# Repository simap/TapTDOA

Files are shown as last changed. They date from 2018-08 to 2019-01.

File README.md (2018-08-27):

TapTDOA
===============

TapTDOA is a project to explore the possibility of making a generic tap interface controller. 

[See Hackaday project for details](https://hackaday.io/project/159821-taptdoa)

License
===============

Portions of the code are provided by third parties, see below for licensing information for those portions. This includes the ARM Math and DSP library as well as STM drivers and HAL code used for setting up the microcontroller.

The MIT License

Copyright (c) 2018 Ben Hencke

Permission is hereby granted, free of charge, to any person obtaining a copy
of this software and associated documentation files (the "Software"), to deal
in the Software without restriction, including without limitation the rights
to use, copy, modify, merge, publish, distribute, sublicense, and/or sell
copies of the Software, and to permit persons to whom the Software is
furnished to do so, subject to the following conditions:

The above copyright notice and this permission notice shall be included in all
copies or substantial portions of the Software.

THE SOFTWARE IS PROVIDED "AS IS", WITHOUT WARRANTY OF ANY KIND, EXPRESS OR
IMPLIED, INCLUDING BUT NOT LIMITED TO THE WARRANTIES OF MERCHANTABILITY,
FITNESS FOR A PARTICULAR PURPOSE AND NONINFRINGEMENT. IN NO EVENT SHALL THE
AUTHORS OR COPYRIGHT HOLDERS BE LIABLE FOR ANY CLAIM, DAMAGES OR OTHER
LIABILITY, WHETHER IN AN ACTION OF CONTRACT, TORT OR OTHERWISE, ARISING FROM,
OUT OF OR IN CONNECTION WITH THE SOFTWARE OR THE USE OR OTHER DEALINGS IN THE
SOFTWARE.

----------

Portions of code are provided by ARM Limited and have the following license:

    Copyright (C) 2010-2015 ARM Limited. All rights reserved.

    $Date:        20. October 2015
    $Revision:    V1.4.5 b

    Project:      CMSIS DSP Library
    Title:        arm_math.h

    Description:  Public header file for CMSIS DSP Library

    Target Processor: Cortex-M7/Cortex-M4/Cortex-M3/Cortex-M0

    Redistribution and use in source and binary forms, with or without
    modification, are permitted provided that the following conditions
    are met:
     - Redistributions of source code must retain the above copyright
       notice, this list of conditions and the following disclaimer.
     - Redistributions in binary form must reproduce the above copyright
       notice, this list of conditions and the following disclaimer in
       the documentation and/or other materials provided with the
       distribution.
     - Neither the name of ARM LIMITED nor the names of its contributors
       may be used to endorse or promote products derived from this
       software without specific prior written permission.

    THIS SOFTWARE IS PROVIDED BY THE COPYRIGHT HOLDERS AND CONTRIBUTORS
    "AS IS" AND ANY EXPRESS OR IMPLIED WARRANTIES, INCLUDING, BUT NOT
    LIMITED TO, THE IMPLIED WARRANTIES OF MERCHANTABILITY AND FITNESS
    FOR A PARTICULAR PURPOSE ARE DISCLAIMED. IN NO EVENT SHALL THE
    COPYRIGHT OWNER OR CONTRIBUTORS BE LIABLE FOR ANY DIRECT, INDIRECT,
    INCIDENTAL, SPECIAL, EXEMPLARY, OR CONSEQUENTIAL DAMAGES (INCLUDING,
    BUT NOT LIMITED TO, PROCUREMENT OF SUBSTITUTE GOODS OR SERVICES;
    LOSS OF USE, DATA, OR PROFITS; OR BUSINESS INTERRUPTION) HOWEVER
    CAUSED AND ON ANY THEORY OF LIABILITY, WHETHER IN CONTRACT, STRICT
    LIABILITY, OR TORT (INCLUDING NEGLIGENCE OR OTHERWISE) ARISING IN
    ANY WAY OUT OF THE USE OF THIS SOFTWARE, EVEN IF ADVISED OF THE
    POSSIBILITY OF SUCH DAMAGE.

---------

Portions of code are provided by STMicroelectronics International N.V. and have the following license:

    Copyright (c) 2018 STMicroelectronics International N.V. 
    All rights reserved.

    Redistribution and use in source and binary forms, with or without 
    modification, are permitted, provided that the following conditions are met:

    1. Redistribution of source code must retain the above copyright notice, 
      this list of conditions and the following disclaimer.
    2. Redistributions in binary form must reproduce the above copyright notice,
      this list of conditions and the following disclaimer in the documentation
      and/or other materials provided with the distribution.
    3. Neither the name of STMicroelectronics nor the names of other 
      contributors to this software may be used to endorse or promote products 
      derived from this software without specific written permission.
    4. This software, including modifications and/or derivative works of this 
      software, must execute solely and exclusively on microcontroller or
      microprocessor devices manufactured by or for STMicroelectronics.
    5. Redistribution and use of this software other than as permitted under 
      this license is void and will automatically terminate your rights under 
      this license. 

    THIS SOFTWARE IS PROVIDED BY STMICROELECTRONICS AND CONTRIBUTORS "AS IS" 
    AND ANY EXPRESS, IMPLIED OR STATUTORY WARRANTIES, INCLUDING, BUT NOT 
    LIMITED TO, THE IMPLIED WARRANTIES OF MERCHANTABILITY, FITNESS FOR A 
    PARTICULAR PURPOSE AND NON-INFRINGEMENT OF THIRD PARTY INTELLECTUAL PROPERTY
    RIGHTS ARE DISCLAIMED TO THE FULLEST EXTENT PERMITTED BY LAW. IN NO EVENT 
    SHALL STMICROELECTRONICS OR CONTRIBUTORS BE LIABLE FOR ANY DIRECT, INDIRECT,
    INCIDENTAL, SPECIAL, EXEMPLARY, OR CONSEQUENTIAL DAMAGES (INCLUDING, BUT NOT
    LIMITED TO, PROCUREMENT OF SUBSTITUTE GOODS OR SERVICES; LOSS OF USE, DATA, 
    OR PROFITS; OR BUSINESS INTERRUPTION) HOWEVER CAUSED AND ON ANY THEORY OF 
    LIABILITY, WHETHER IN CONTRACT, STRICT LIABILITY, OR TORT (INCLUDING 
    NEGLIGENCE OR OTHERWISE) ARISING IN ANY WAY OUT OF THE USE OF THIS SOFTWARE,
    EVEN IF ADVISED OF THE POSSIBILITY OF SUCH DAMAGE.

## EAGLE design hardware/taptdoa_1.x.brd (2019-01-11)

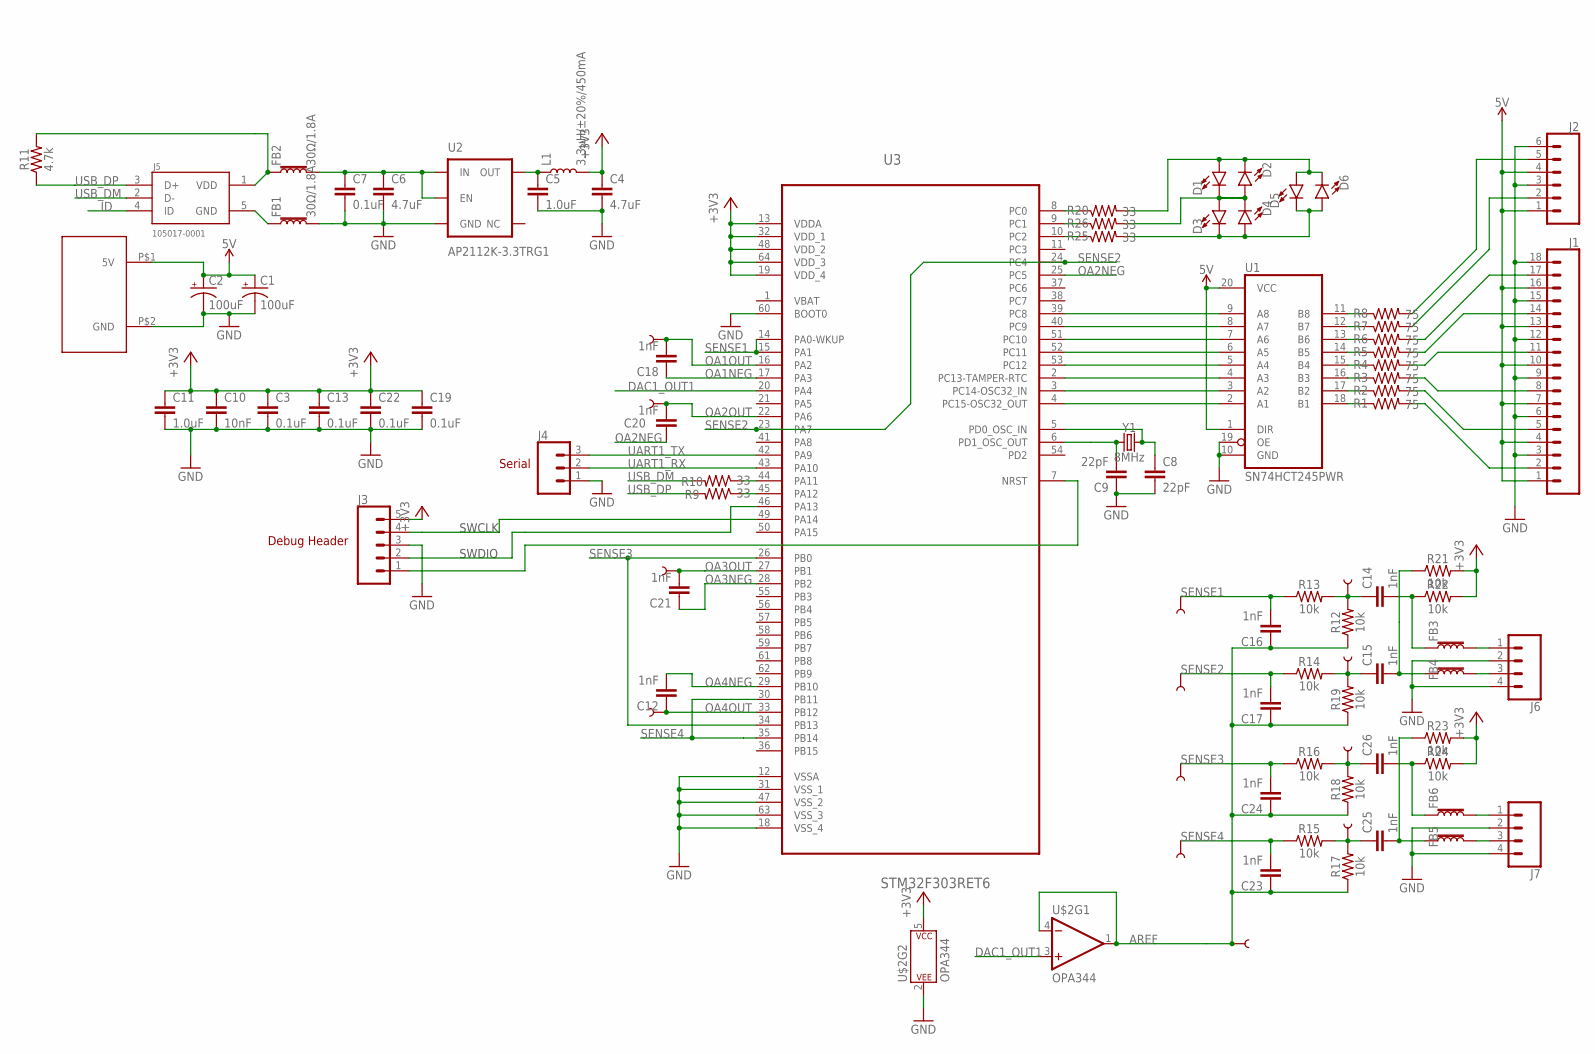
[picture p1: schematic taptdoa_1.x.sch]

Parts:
C1, C2: 100uF; PANASONIC_D
C3, C7, C13, C19, C22: 0.1uF; 0603
C4, C6: 4.7uF; 0603
C5, C11: 1.0uF; 0603
C8, C9: 22pF; 0603
C10: 10nF; 0603
C12, C14, C15, C16, C17, C18, C20, C21, C23, C24, C25, C26: 1nF; 0603
D1, D2, D3, D4, D5, D6: LED0603; LED-0603
FB1, FB2, FB3, FB4, FB5, FB6: 30Ω/1.8A; 0603
J1: CONN_18; 1X18
J2: CONN_06LOCK; 1X06_LOCK
J3: CONN_05LOCK; 1X05_LOCK
J4: CONN_03; 1X03
J5: 105017-0001; MOLEX_105017-0001
J6, J7: CONN_04LOCK_LONGPADS; 1X04_LOCK_LONGPADS
L1: 3.3µH/±20%/450mA; 0805
R1, R2, R3, R4, R5, R6, R7, R8: 75; 0603
R9, R10, R20, R25, R26: 33; 0603
R11: 4.7k; 0603
R12, R13, R14, R15, R16, R17, R18, R19, R21, R22, R23, R24: 10k; 0603
TP1, TP2, TP3, TP4, TP5, TP6, TP7, TP8, TP9, TP10, TP11, TP12, TP13: TEST-POINT3X4; PAD.03X.04
U1: SN74HCT245PWR; TSSOP20
U2: AP2112K-3.3TRG1; SOT23-5
U3: STM32F303RET6; QFP50P1200X1200X160-64N
U$1: XT30XT30_THRUHOLE; ZT30
U$2: OPA344; SOT23-5
Y1: 8MHz; HC49UP

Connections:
5V: C1.+, C2.+, J1.1, J1.4, J1.7, J1.10, J1.13, J1.16, J2.1, J2.4, U1.1 (DIR), U1.20 (VCC), U$1.P$1 (5V)
+3V3: C3.1, C4.1, C10.1, C11.1, C13.1, C19.1, C22.1, J3.5, L1.2, R21.2, R22.2, R23.2, R24.2, U3.13 (VDDA), U3.19 (VDD_4), U3.32 (VDD_1), U3.48 (VDD_2), U3.64 (VDD_3), U$2.5 (P$V+)
AREF: C16.1, C17.1, C23.1, C24.1, R12.1, R17.1, R18.1, R19.1, TP8.P$1, U$2.1 (OUT), U$2.4 (-IN)
DAC1_OUT1: U3.20 (PA4), U$2.3 (+IN)
GND: C1.-, C2.-, C3.2, C4.2, C5.2, C6.2, C7.2, C8.2, C9.1, C10.2, C11.2, C13.2, C19.2, C22.2, FB1.2, J1.3, J1.6, J1.9, J1.12, J1.15, J1.18, J2.3, J2.6, J3.3, J4.1, J6.2, J6.4, J7.2, J7.4, U1.10 (GND), U1.19 (OE), U2.2 (GND), U3.12 (VSSA), U3.18 (VSS_4), U3.31 (VSS_1), U3.47 (VSS_2), U3.60 (BOOT0), U3.63 (VSS_3), U$1.P$2 (GND), U$2.2 (P$V-)
HP1: C14.1, R12.2, R13.2, TP2.P$1
HP2: C15.1, R14.2, R19.2, TP3.P$1
HP3: C26.1, R16.2, R18.2, TP12.P$1
HP4: C25.1, R15.2, R17.2, TP13.P$1
ID: J5.4 (ID)
LED0: J1.2, R1.2
LED1: J1.5, R2.2
LED2: J1.8, R3.2
LED3: J1.11, R4.2
LED4: J1.14, R5.2
LED5: J1.17, R6.2
unnamed: R20.1, U3.8 (PC0)
unnamed: D1.A, D2.C, D5.A, D6.C, R20.2
unnamed: R25.1, U3.10 (PC2)
unnamed: R26.1, U3.9 (PC1)
unnamed: D1.C, D2.A, D3.A, D4.C, R26.2
unnamed: R10.1, U3.44 (PA11)
unnamed: R9.1, U3.45 (PA12)
unnamed: FB1.1, J5.5 (GND)
unnamed: C5.1, L1.1, U2.5 (OUT)
unnamed: R1.1, U1.18 (B1)
unnamed: R2.1, U1.17 (B2)
unnamed: R3.1, U1.16 (B3)
unnamed: R4.1, U1.15 (B4)
unnamed: R5.1, U1.14 (B5)
unnamed: R6.1, U1.13 (B6)
unnamed: C14.2, FB3.1, R22.1
unnamed: C26.2, FB6.1, R24.1
unnamed: C15.2, FB4.1, R21.1
unnamed: D3.C, D4.A, D5.C, D6.A, R25.2
unnamed: C25.2, FB5.1, R23.1
unnamed: R7.1, U1.12 (B7)
unnamed: R8.1, U1.11 (B8)
unnamed: J2.2, R7.2
unnamed: J2.5, R8.2
unnamed: FB3.2, J6.1
unnamed: FB6.2, J7.1
unnamed: FB5.2, J7.3
unnamed: FB4.2, J6.3
NRST: J3.1, U3.7 (NRST)
OA1NEG: C18.1, U3.17 (PA3)
OA1OUT: C18.2, TP6.P$1, U3.16 (PA2)
OA2NEG: C20.1, U3.25 (PC5)
OA2OUT: C20.2, TP7.P$1, U3.22 (PA6)
OA3NEG: C21.1, U3.28 (PB2)
OA3OUT: C21.2, TP9.P$1, U3.27 (PB1)
OA4NEG: C12.2, U3.29 (PB10)
OA4OUT: C12.1, TP1.P$1, U3.33 (PB12)
PA13: J3.2, U3.46 (PA13)
PA14: J3.4, U3.49 (PA14)
PC8: U1.9 (A8), U3.39 (PC8)
PC9: U1.8 (A7), U3.40 (PC9)
PC10: U1.7 (A6), U3.51 (PC10)
PC11: U1.6 (A5), U3.52 (PC11)
PC12: U1.5 (A4), U3.53 (PC12)
PC13: U1.4 (A3), U3.2 (PC13-TAMPER-RTC)
PC14: U1.3 (A2), U3.3 (PC14-OSC32_IN)
PC15: U1.2 (A1), U3.4 (PC15-OSC32_OUT)
PD0_OSC_IN: C8.1, U3.5 (PD0_OSC_IN), Y1.2
PD1_OSC_OUT: C9.2, U3.6 (PD1_OSC_OUT), Y1.1
SENSE1: C16.2, R13.1, TP4.P$1, U3.14 (PA0-WKUP), U3.15 (PA1)
SENSE2: C17.2, R14.1, TP5.P$1, U3.23 (PA7), U3.24 (PC4)
SENSE3: C24.2, R16.1, TP10.P$1, U3.26 (PB0), U3.34 (PB13)
SENSE4: C23.2, R15.1, TP11.P$1, U3.30 (PB11), U3.35 (PB14)
UART1_RX: J4.2, U3.43 (PA10)
UART1_TX: J4.3, U3.42 (PA9)
USB_DM: J5.2 (D-), R10.2
USB_DP: J5.3 (D+), R9.2, R11.1
VUSB: FB2.1, J5.1 (VDD), R11.2
VUSB2: C6.1, C7.1, FB2.2, U2.1 (IN), U2.3 (EN)

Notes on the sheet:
SWDIO
SWCLK
Debug Header
Serial

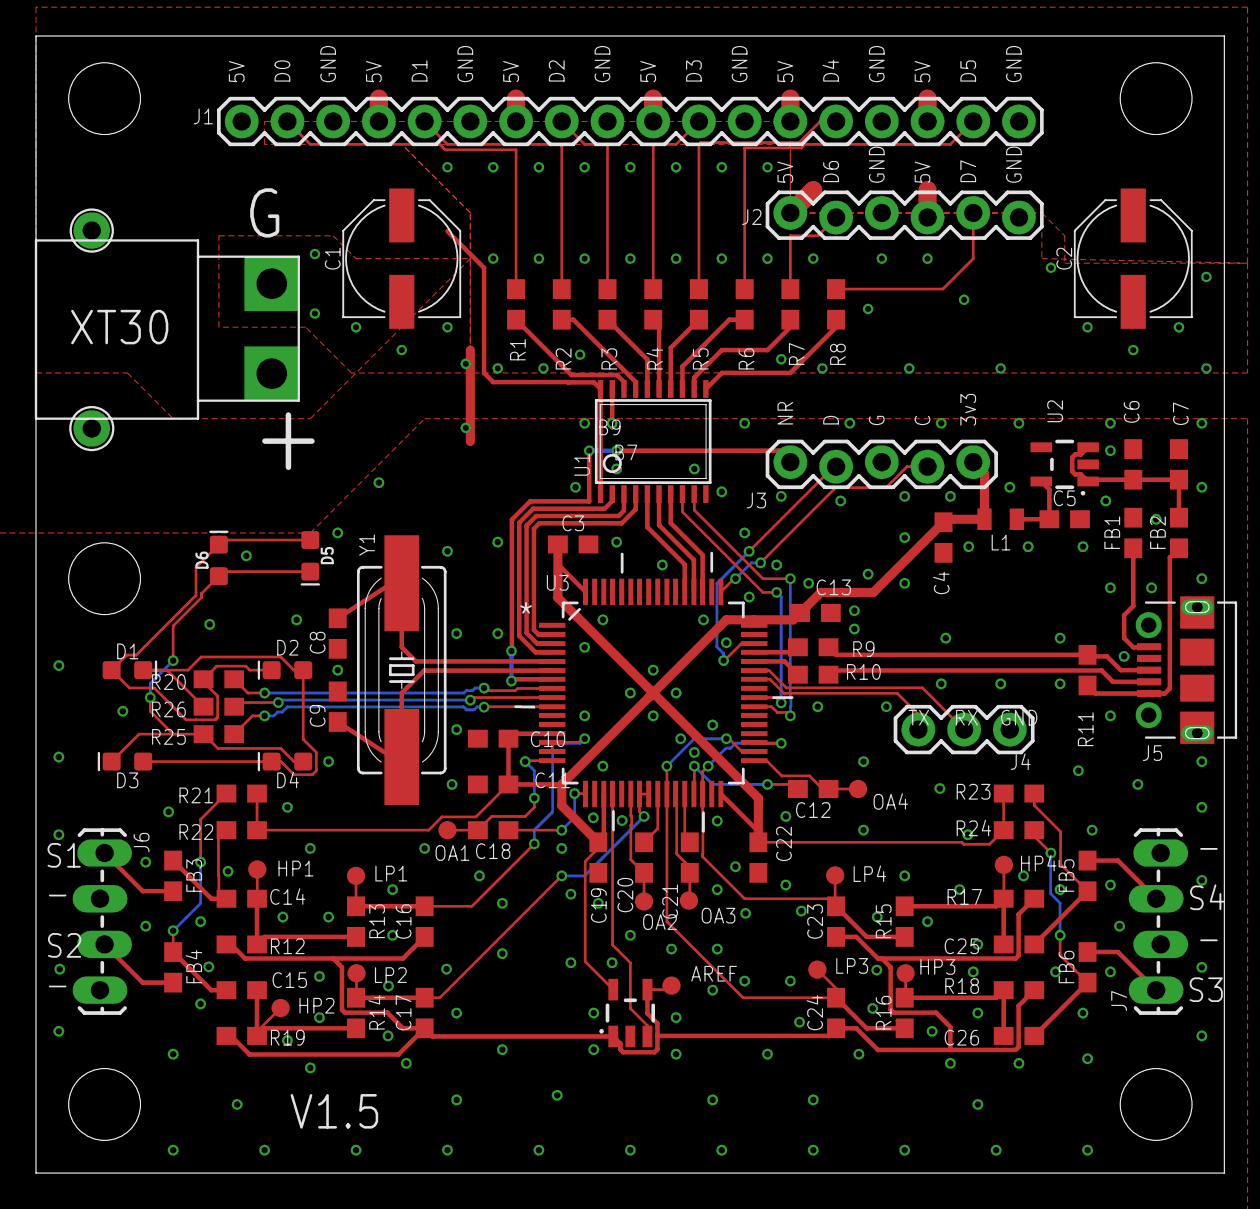
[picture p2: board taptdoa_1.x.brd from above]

Board: 2 copper layers, 66.0 x 63.2 mm, 91 parts (0 on the bottom side), 74 nets.

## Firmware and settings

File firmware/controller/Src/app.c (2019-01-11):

#include "stm32f3xx_hal.h"
#include "usb_device.h"
#include "pixelBlaster.h"
#include "console.h"


#include "app.h"


int _write(int file, char *outgoing, int len);

extern ADC_HandleTypeDef hadc1;
extern ADC_HandleTypeDef hadc2;
extern ADC_HandleTypeDef hadc3;
extern ADC_HandleTypeDef hadc4;
extern DMA_HandleTypeDef hdma_adc1;
extern DMA_HandleTypeDef hdma_adc2;
extern DMA_HandleTypeDef hdma_adc3;
extern DMA_HandleTypeDef hdma_adc4;

extern DAC_HandleTypeDef hdac1;

extern OPAMP_HandleTypeDef hopamp1;
extern OPAMP_HandleTypeDef hopamp2;
extern OPAMP_HandleTypeDef hopamp3;
extern OPAMP_HandleTypeDef hopamp4;

extern TIM_HandleTypeDef htim4;
extern DMA_HandleTypeDef hdma_tim4_up;

extern UART_HandleTypeDef huart1;

extern const uint16_t sample1[];
extern const uint16_t sample2[];
extern const uint16_t sample3[];
extern const uint16_t sample4[];

#define LED_BUFFER_SIZE (40*24*8/2)
uint8_t ledBuffer[LED_BUFFER_SIZE];
PixelBlasterData pb;


int16_t cbuf[4][ADC_BUF_SIZE];

static volatile bool triggerDone = false;
int dmaCndtr;

volatile uint32_t ms;
uint32_t lastHitMs = 0;

volatile enum {
	WAITING, CAPTURING, IGNORENEXT
} triggerMode;

/*
 * Set up timer 3 to trigger all ADCs at the same time.
 * simultaneously capture all channels
 * It also seems like it will be more controllable than continuous mode.
 * DMA buffers won't need too much upkeep, should mostly run w/o cpu
 * Use adc watchdog 1 on each adc to trigger captureEvent()
 *
 *           trigger   +------+ dma   +---------------+
 *           +-------> | adc1 +------>+  circ buffer  |
 *           |         +------+       +---------------+
 *           |         +------+ dma   +---------------+
 *           +-------> | adc2 +------>+  circ buffer  |
 * +------+  |         +------+       +---------------+
 * | tim3 +--+         +------+ dma   +---------------+
 * +------+  +-------> | adc3 +------>+  circ buffer  |
 *           |         +------+       +---------------+
 *           |         +------+ dma   +---------------+
 *           +-------> | adc4 +------>+  circ buffer  |
 *                     +--+---+       +---------------+
 *                        |
 *                        |adc 1-4 watchdogs
 *                        +------------------->  captureEvent()
 *
 * When event fires, make note of current dma CNDTR indicating where the circular buffer is at the trigger start
 * start countdown on tim3 triggers until we have the trailing data captured
 * then stop tim3 to process the buffer
 *
 * TODO is it possible one adc triggered an event and there's nothing on the others?
 * TODO any issue with being "blind" during processing/sending?
 * TODO ws2812: if we need to interrupt at 800khz, thats about every 90 cycles. too much? maybe clock stretch?
 */

void setAdcWd() {
	int w = 1300, m;
	uint32_t tr1;

	m = getMeian(0);
	tr1 = ((m + w) << 16) | (m - w);
	ADC1->TR1 = tr1;

	m = getMeian(1);
	tr1 = ((m + w) << 16) | (m - w);
	ADC2->TR1 = tr1;

	m = getMeian(2);
	tr1 = ((m + w) << 16) | (m - w);
	ADC3->TR1 = tr1;

	m = getMeian(3);
	tr1 = ((m + w) << 16) | (m - w);
	ADC4->TR1 = tr1;
}

void setOpAmpGainAndDac(int gain) {

	//	VM_SEL
	//	10: Resistor feedback output (PGA mode)
	//	11: follower mode
	uint32_t csr = 0;
	switch(gain) {
		case 1:
			csr = 0b11 << OPAMP1_CSR_VMSEL_Pos; //set to follower
			break;
		case 2:
			csr = OPAMP_PGA_GAIN_2 | 0b10 << OPAMP1_CSR_VMSEL_Pos;
			break;
		case 4:
			csr = OPAMP_PGA_GAIN_4 | 0b10 << OPAMP1_CSR_VMSEL_Pos;
			break;
		case 8:
			csr = OPAMP_PGA_GAIN_8 | 0b10 << OPAMP1_CSR_VMSEL_Pos;
			break;
		case 16:
			csr = OPAMP_PGA_GAIN_16 | 0b10 << OPAMP1_CSR_VMSEL_Pos;
			break;
		default:
			HardFault_Handler();
	}

	HAL_DACEx_DualSetValue(&hdac1, DAC_ALIGN_12B_R, 2048/gain, 2048/gain);

	MODIFY_REG(hopamp1.Instance->CSR, OPAMP_CSR_PGGAIN_Msk | OPAMP_CSR_VMSEL_Msk, csr);
	MODIFY_REG(hopamp2.Instance->CSR, OPAMP_CSR_PGGAIN_Msk | OPAMP_CSR_VMSEL_Msk, csr);
	MODIFY_REG(hopamp3.Instance->CSR, OPAMP_CSR_PGGAIN_Msk | OPAMP_CSR_VMSEL_Msk, csr);
	MODIFY_REG(hopamp4.Instance->CSR, OPAMP_CSR_PGGAIN_Msk | OPAMP_CSR_VMSEL_Msk, csr);

}

void setup() {

	pbInit(&pb, ledBuffer, LED_BUFFER_SIZE);
	memset(ledBuffer, 0, LED_BUFFER_SIZE);

	HAL_DACEx_DualSetValue(&hdac1, DAC_ALIGN_12B_R, 2048/4, 2048/4);

//	setOpAmpGainAndDac(4);

//	MODIFY_REG(hopamp1.Instance->CSR, OPAMP_CSR_PGGAIN_Msk, OPAMP_PGA_GAIN_2);
//	MODIFY_REG(hopamp2.Instance->CSR, OPAMP_CSR_PGGAIN_Msk, OPAMP_PGA_GAIN_2);
//	MODIFY_REG(hopamp3.Instance->CSR, OPAMP_CSR_PGGAIN_Msk, OPAMP_PGA_GAIN_2);
//	MODIFY_REG(hopamp4.Instance->CSR, OPAMP_CSR_PGGAIN_Msk, OPAMP_PGA_GAIN_2);

	HAL_DAC_Start(&hdac1, DAC_CHANNEL_1);

	HAL_Delay(100);

	HAL_ADCEx_Calibration_Start(&hadc1, ADC_SINGLE_ENDED);
	HAL_ADCEx_Calibration_Start(&hadc2, ADC_SINGLE_ENDED);
	HAL_ADCEx_Calibration_Start(&hadc3, ADC_SINGLE_ENDED);
	HAL_ADCEx_Calibration_Start(&hadc4, ADC_SINGLE_ENDED);

	//TODO try without calibrating, seems off anyway.
	HAL_OPAMP_SelfCalibrate(&hopamp1);
	HAL_OPAMP_SelfCalibrate(&hopamp2);
	HAL_OPAMP_SelfCalibrate(&hopamp3);
	HAL_OPAMP_SelfCalibrate(&hopamp4);

	HAL_OPAMP_Start(&hopamp1);
	HAL_OPAMP_Start(&hopamp2);
	HAL_OPAMP_Start(&hopamp3);
	HAL_OPAMP_Start(&hopamp4);

	HAL_ADC_Start_DMA(&hadc1, (uint32_t *) &cbuf[0][0], ADC_BUF_SIZE);
	HAL_ADC_Start_DMA(&hadc2, (uint32_t *) &cbuf[1][0], ADC_BUF_SIZE);
	HAL_ADC_Start_DMA(&hadc3, (uint32_t *) &cbuf[2][0], ADC_BUF_SIZE);
	HAL_ADC_Start_DMA(&hadc4, (uint32_t *) &cbuf[3][0], ADC_BUF_SIZE);

	disarmAdcWatchdogs();



	//let things settle on powerup
	HAL_Delay(100);

//	DBGMCU->APB1FZ = 0xffff;
//	DBGMCU->APB2FZ = 0xffff;

	LL_TIM_ClearFlag_UPDATE(TIM3);
	LL_TIM_EnableIT_UPDATE(TIM3);

	LL_TIM_ClearFlag_UPDATE(TIM2);
	LL_TIM_EnableIT_UPDATE(TIM2);

	LL_TIM_EnableCounter(TIM3);
	LL_TIM_EnableCounter(TIM4);

	//tim4 is used to spit out pixel data to gpio
	TIM4->DIER |= TIM_DIER_UDE; //Update DMA request enable
	HAL_TIM_Base_Start(&htim4);

	HAL_Delay(100);

	seedMeans(cbuf);

	setAdcWd();
	armAdcWatchdogs();
}

void disarmAdcWatchdogs(void) {
	CLEAR_BIT(hadc1.Instance->IER, ADC_IER_AWD1IE);
	CLEAR_BIT(hadc2.Instance->IER, ADC_IER_AWD1IE);
	CLEAR_BIT(hadc3.Instance->IER, ADC_IER_AWD1IE);
	CLEAR_BIT(hadc4.Instance->IER, ADC_IER_AWD1IE);
}

void armAdcWatchdogs(void) {
	CLEAR_BIT(ADC1->ISR, ADC_ISR_AWD1);
	CLEAR_BIT(ADC2->ISR, ADC_ISR_AWD1);
	CLEAR_BIT(ADC3->ISR, ADC_ISR_AWD1);
	CLEAR_BIT(ADC4->ISR, ADC_ISR_AWD1);

	SET_BIT(hadc1.Instance->IER, ADC_IER_AWD1IE);
	SET_BIT(hadc2.Instance->IER, ADC_IER_AWD1IE);
	SET_BIT(hadc3.Instance->IER, ADC_IER_AWD1IE);
	SET_BIT(hadc4.Instance->IER, ADC_IER_AWD1IE);
}



uint32_t helloTimer;

void loop() {
	if (ms - helloTimer > 5000) {
		helloTimer = ms;
		printf("hi\n");
		flushConsole();
	}

#if 0
	memcpy(cbuf[0], sample1 + 1500, ADC_BUF_SIZE * sizeof(q15_t));
	memcpy(cbuf[1], sample2 + 1500, ADC_BUF_SIZE * sizeof(q15_t));
	memcpy(cbuf[2], sample3 + 1500, ADC_BUF_SIZE * sizeof(q15_t));
	memcpy(cbuf[3], sample4 + 1500, ADC_BUF_SIZE * sizeof(q15_t));

	analyzeDelays(cbuf, 0);
	HAL_Delay(1000);

	return;

#endif

	if (HAL_DMA_GetState(&hdma_tim4_up) == HAL_DMA_STATE_READY && pbCheckDone(&pb)) {
		//TODO reset the timer counter or it can cut clocks, this seems to transfer immediately
		htim4.Instance->CNT = 0;
		HAL_DMA_Start_IT(&hdma_tim4_up, (uint32_t) ledBuffer, ((uint32_t)&GPIOC->ODR) + 1, LED_BUFFER_SIZE);
	}

	if (triggerDone) {
		if (ms - lastHitMs > 500) {

			int res = analyzeDelays(cbuf, dmaCndtr);

			flushConsole();
#if 0
			printf("Raw data:\nch1\tch2\tch3\tch4\n");

			union {
				uint32_t vars[4];
				char bytes[20];
			} buf;

			for (int i = 0; i < ADC_BUF_SIZE; i++) {
				int index = (ADC_BUF_SIZE + i - dmaCndtr + 1) % ADC_BUF_SIZE;
				buf.vars[0] = hexShort(cbuf[0][index]);
				buf.vars[1] = hexShort(cbuf[1][index]);
				buf.vars[2] = hexShort(cbuf[2][index]);
				buf.vars[3] = hexShort(cbuf[3][index]);
				buf.bytes[16] = '\n';
				_write(0, buf.bytes, 17);
			}
			printf("=========\n");
			flushConsole();
#endif
			lastHitMs = ms;
		}

		LL_TIM_EnableCounter(TIM3);
		HAL_Delay(2);

		triggerDone = false;
		//TODO figure out why adc watchdog keeps firing immediately after it gets reenabled
		triggerMode = WAITING;
		armAdcWatchdogs();
	}

}

void startEventCapture() {

	disarmAdcWatchdogs();
	triggerMode = CAPTURING;

	LL_TIM_EnableCounter(TIM2);
}

//called from TIM2_IRQHandler
void stopEventCapture() {
	if (triggerMode == CAPTURING) {
		LL_TIM_DisableCounter(TIM3);
		triggerDone = true;
		dmaCndtr = hdma_adc1.Instance->CNDTR; //these should all be the same
	}
}

void HAL_ADC_LevelOutOfWindowCallback(ADC_HandleTypeDef* hadc) {
	startEventCapture();
}

void HAL_SYSTICK_Callback() {
	ms++;
}

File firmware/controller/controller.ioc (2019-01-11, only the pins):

Mcu.UserName=STM32F303RETx
PA0.Signal=ADC1_IN1
PA1.Signal=OPAMP1_VINP
PA10.GPIO_Label=uartRx
PA10.Signal=USART1_RX
PA11.Signal=USB_DM
PA12.Signal=USB_DP
PA13.Signal=SYS_JTMS-SWDIO
PA14.Signal=SYS_JTCK-SWCLK
PA2.Signal=OPAMP1_VOUT
PA3.Signal=OPAMP1_VINM
PA4.Signal=COMP_DAC11_group
PA5.Signal=COMP_DAC12_group
PA6.Signal=OPAMP2_VOUT
PA7.Signal=OPAMP2_VINP
PA9.GPIO_Label=uartTx
PA9.Signal=USART1_TX
PB0.Signal=OPAMP3_VINP
PB1.Signal=OPAMP3_VOUT
PB10.Signal=OPAMP4_VINM
PB11.Signal=OPAMP4_VINP
PB12.Signal=OPAMP4_VOUT
PB13.Signal=ADC3_IN5
PB14.Signal=ADC4_IN4
PB2.Signal=OPAMP3_VINM
PC0.Signal=S_TIM1_CH1
PC1.Signal=S_TIM1_CH2
PC10.Signal=GPIO_Output
PC11.Signal=GPIO_Output
PC12.Signal=GPIO_Output
PC13.Signal=GPIO_Output
PC14-OSC32_IN.Signal=GPIO_Output
PC15-OSC32_OUT.Signal=GPIO_Output
PC4.Signal=ADC2_IN5
PC5.Signal=OPAMP2_VINM
PC8.Signal=GPIO_Output
PC9.Signal=GPIO_Output
PF0-OSC_IN.Signal=RCC_OSC_IN
PF1-OSC_OUT.Signal=RCC_OSC_OUT

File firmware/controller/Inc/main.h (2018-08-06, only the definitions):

#define uartTx_Pin GPIO_PIN_9
#define uartTx_GPIO_Port GPIOA
#define uartRx_Pin GPIO_PIN_10
#define uartRx_GPIO_Port GPIOA

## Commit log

2018-08-06 initial
    set up all the peripherals
    trigger on ADC WD
    start timer to capture some following data
    spit out raw data over usb serial console
    boards with some fixes
    [controller Debug.cfg, taptdoa_1.x.brd, taptdoa_1.x.sch]
2018-08-27 v1.2 of board
    [taptdoa_1.x.brd, taptdoa_1.x.sch]
2018-09-18 working on LEDs, simple threshold detection for now, limited filtering
    [taptdoa_1.x.brd, taptdoa_1.x.sch]
2018-10-16 re layout board
    [taptdoa_1.x.brd, taptdoa_1.x.sch]
2018-10-16 cleanup renumber
    [taptdoa_1.x.brd, taptdoa_1.x.sch]
2018-10-16 update code for new board rev
    move led data to port c
    extra analog channels
    sampling time
2018-10-19 ws2812 timer
2018-11-06 fix circular buffer dump, led timing
    [app.c]
2018-11-10 50khz sample, 2khz target. more debug data
2018-11-27 new board rev with leds, fix swd pins
    [taptdoa_1.x.brd, taptdoa_1.x.sch]
2019-01-11 more LEDs
    [taptdoa_1.x.brd, taptdoa_1.x.sch]
2019-01-11 fix minor drc
    [taptdoa_1.x.brd, taptdoa_1.x.sch]

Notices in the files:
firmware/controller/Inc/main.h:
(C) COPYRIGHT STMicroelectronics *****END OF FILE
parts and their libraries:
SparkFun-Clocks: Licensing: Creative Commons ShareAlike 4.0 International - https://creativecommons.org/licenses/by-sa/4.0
